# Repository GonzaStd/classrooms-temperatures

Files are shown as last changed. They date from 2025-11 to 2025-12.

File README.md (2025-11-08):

> [!IMPORTANT]  
> This project has been made for a specific purpose. If you want to replicate this, you would have to ADAPT IT. However, example code and circuit documentation are provided below on the index, and they are for general use. 

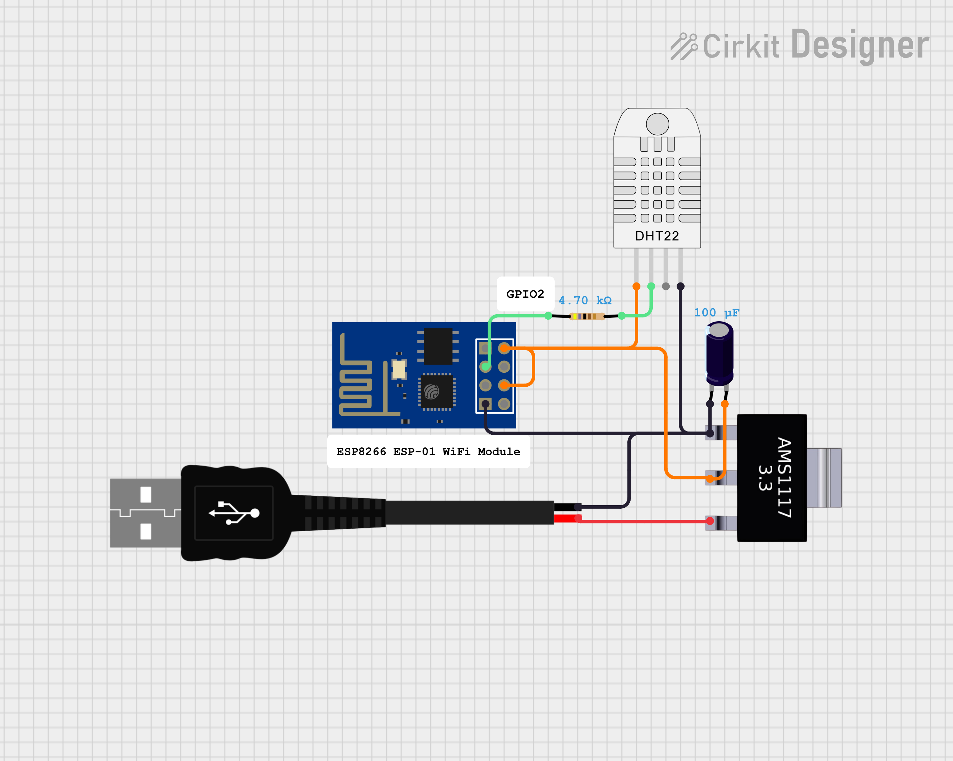
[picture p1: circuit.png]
Circuit diagram


[Here](https://app.cirkitdesigner.com/project/02f16717-05df-46d2-9647-529fff1c8d03) is the url of the circuit.

### Index
* [Circuit Explaination](docs/circuit.md)
* [Example code for general use](docs/example-code.md)

## Context
With the purpose of measuring the temperature of classrooms in our school (and so the thermal discomfort), I've made this project that connects esp-01 modules that act like mqtt clients that publishes temperature and humidity, and by the other side subscribes to a topic they use to know WHEN to send data. 

On the other hand, we'll need a broker, in this case I'll use a Raspberry Pi. This one has to send a request to their clients, receive temperature and humidity, then upload the data to a Google Spreadsheet. 

After a few months, this data will be used to analyse the thermal discomfort and then a request will be sent asking the authorities to allow the placement of rotating fans and curtains (currently there are few fans, they do not rotate and there are no curtains).

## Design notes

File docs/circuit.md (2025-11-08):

# Circuit documentation

## Summary

This circuit interfaces an ESP8266 ESP-01 Wi‑Fi module with a DHT22 temperature & humidity sensor. The ESP8266 connects to Wi‑Fi and publishes sensor readings to an MQTT broker. Power comes from USB and is regulated to 3.3V using an AMS1117. A pull-up resistor is used on the DHT22 data line.

## Components

1. ESP8266 ESP-01
	- Description: Small Wi‑Fi module used to connect to a network and run the MQTT client.
	- Pins: `TXD`, `CH_PD`, `RST`, `VCC`, `GND`, `GPIO_2`, `GPIO_0`, `RXD`

2. DHT22 (temperature & humidity sensor)
	- Description: Digital temperature and humidity sensor.
	- Pins: `VCC`, `DATA`, `NC`, `GND`

3. Pull-up resistor (for DHT22 data line)
	- Description: Pull-up resistor for the DHT22 data line.
	- Value: 4.7 kΩ (4700 Ω)
	- Pins: `pin1`, `pin2`

4. USB 2‑pin power connector
	- Description: Provides 5V power from a USB source.
	- Pins: `V+` (Positive), `GND` (Negative)

5. AMS1117 3.3V regulator
	- Description: Regulates USB 5V down to 3.3V for the ESP8266 and sensor.
	- Pins: `GND`, `OUT` (3.3V), `IN` (5V)

6. Electrolytic capacitor
	- Description: Voltage stabilization on the regulator output.
	- Typical value: 100 µF (0.0001 F)
	- Polarity: `-` (negative), `+` (positive)

## Wiring details

### ESP8266 (ESP-01)
 - `GND`: connect to regulator GND, USB GND, DHT22 GND, and capacitor `-`.
 - `CH_PD` (chip enable): tie to `VCC` (3.3V).
 - `VCC`: connect to AMS1117 `OUT` (3.3V).
 - `GPIO_0`: used for programming mode; if used for the DHT/data wiring follow your firmware wiring (commonly not used by the DHT data line). Ensure correct logic level for boot.

### DHT22
 - `VCC`: connect to AMS1117 `OUT` (3.3V).
 - `DATA`: connect to the microcontroller data pin through a pull-up resistor (4.7 kΩ to 3.3V).
 - `GND`: connect to system GND.

### Pull-up resistor
 - `pin1`: connected to the DHT22 `DATA` line (or microcontroller input if placed there).
 - `pin2`: connected to `VCC` (3.3V) as the pull-up.

### USB power connector
 - `GND` (Negative): connect to system GND.
 - `V+` (Positive): connect to AMS1117 `IN` (5V from USB).

### AMS1117 3.3V regulator
 - `GND`: system ground.
 - `OUT`: 3.3V output — connect to ESP8266 `VCC`, DHT22 `VCC`, capacitor `+`.
 - `IN`: 5V input from USB `V+`.

### Electrolytic capacitor
 - `-` (negative): connect to system GND.
 - `+` (positive): connect to AMS1117 `OUT` (3.3V) for smoothing.

---

Notes:
- Use a common ground for all modules.
- The DHT22 data line requires a pull-up (4.7 kΩ is a standard choice). Place the pull-up between DATA and 3.3V.
- Ensure the ESP8266 receives a stable 3.3V supply and that the regulator can supply sufficient current (ESP8266 can spike during Wi‑Fi transmissions).

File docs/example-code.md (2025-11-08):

# Generic and example code
This code is an example of what you could use to flash the ESP-01 firmware and use it with the circuit shown below. This is NOT the code upload on this repository, this is for general use.

```cpp
#include <ESP8266WiFi.h>
#include <PubSubClient.h>
#include <DHT.h>

#define DHTPIN D2          // Pin where the DHT22 is connected
#define DHTTYPE DHT22     // DHT 22 (AM2302)

// Wi-Fi credentials
const char* ssid = "yourSSID";
const char* password = "yourPASSWORD";

// MQTT server details
const char* mqttServer = "mqttServer";
const int mqttPort = 1883; // Default MQTT port
const char* topic = "sensor/data";

DHT dht(DHTPIN, DHTTYPE);
WiFiClient espClient;
PubSubClient client(espClient);

void setup() {
  Serial.begin(9600);
  dht.begin();
  setupWiFi();
  client.setServer(mqttServer, mqttPort);
}

void setupWiFi() {
  delay(10);
  Serial.println();
  Serial.print("Connecting to ");
  Serial.println(ssid);
  
  WiFi.begin(ssid, password);
  
  while (WiFi.status() != WL_CONNECTED) {
    delay(500);
    Serial.print(".");
  }
  
  Serial.println();
  Serial.println("WiFi connected");
}

void loop() {
  if (!client.connected()) {
    reconnect();
  }
  client.loop();

  float h = dht.readHumidity();
  float t = dht.readTemperature();

  if (isnan(h) || isnan(t)) {
    Serial.println("Failed to read from DHT sensor!");
    return;
  }

  String payload = String("Temperature: ") + t + " °C, Humidity: " + h + " %";
  client.publish(topic, payload.c_str());
  
  delay(2000); // Publish every 2 seconds
}

void reconnect() {
  while (!client.connected()) {
    Serial.print("Attempting MQTT connection...");
    if (client.connect("ESP8266Client")) {
      Serial.println("connected");
    } else {
      Serial.print("failed, rc=");
      Serial.print(client.state());
      Serial.println(" try again in 5 seconds");
      delay(5000);
    }
  }
}
```

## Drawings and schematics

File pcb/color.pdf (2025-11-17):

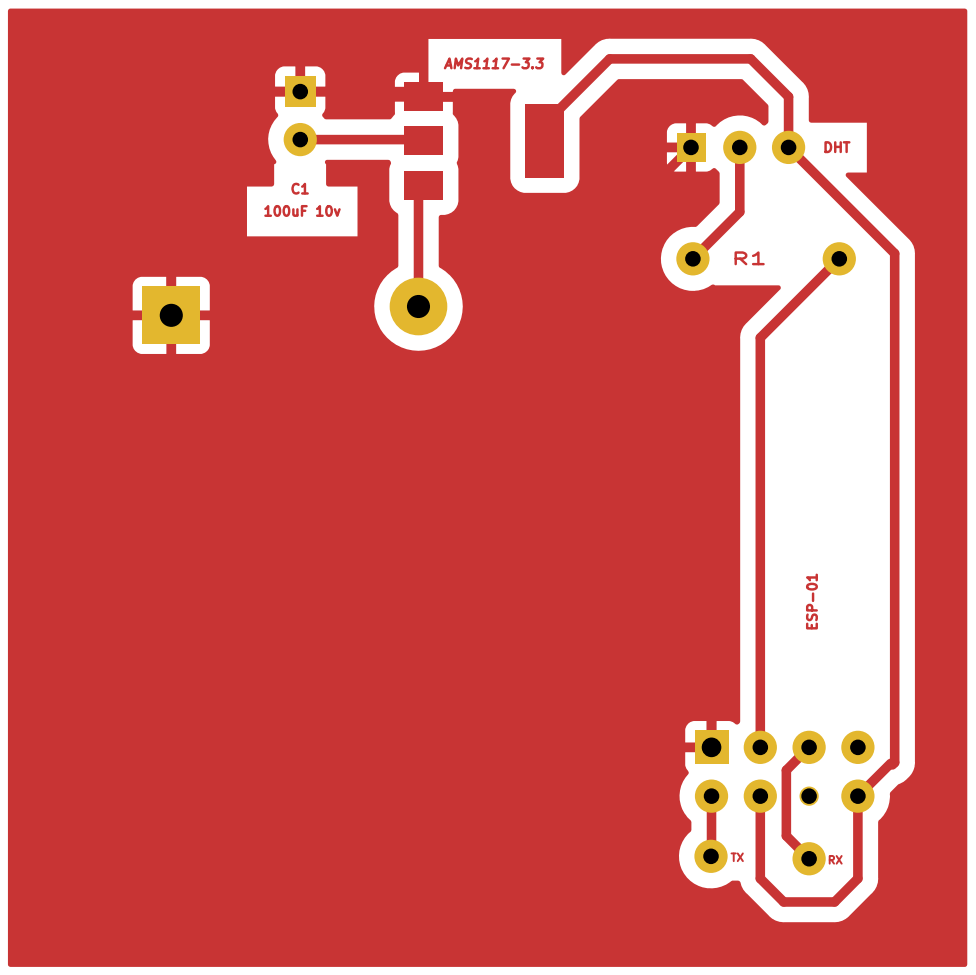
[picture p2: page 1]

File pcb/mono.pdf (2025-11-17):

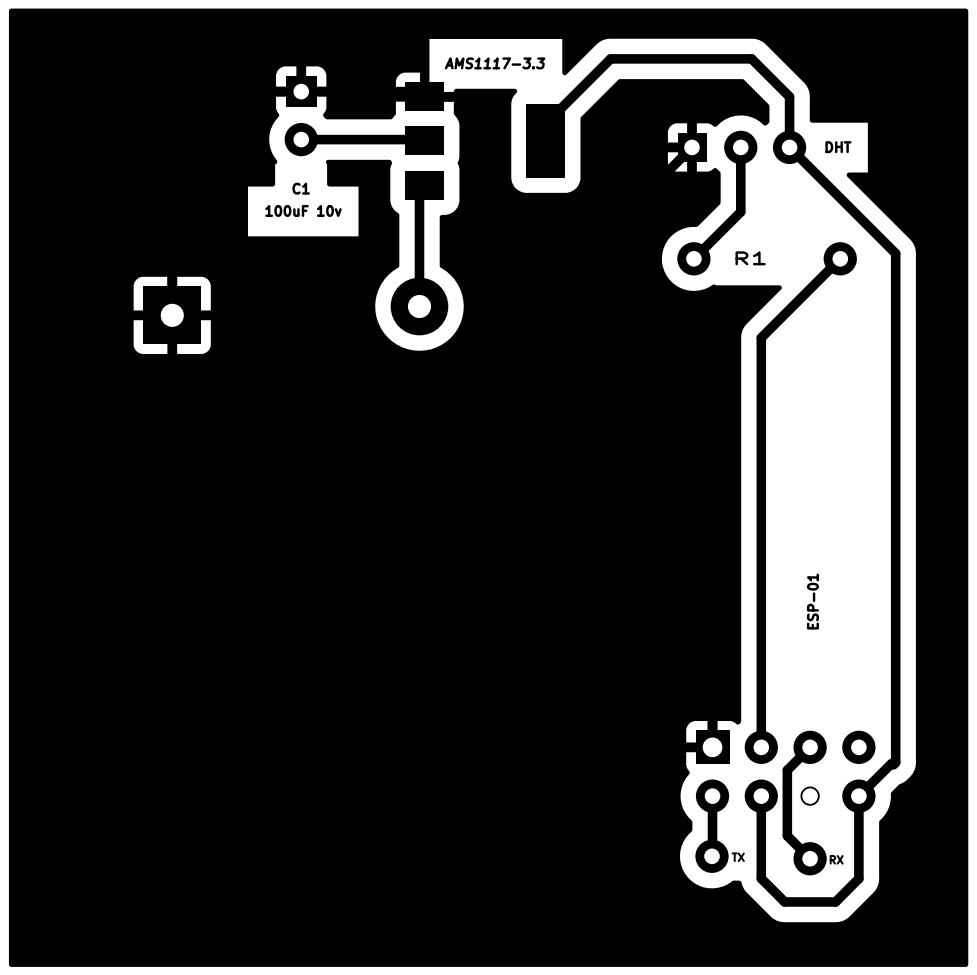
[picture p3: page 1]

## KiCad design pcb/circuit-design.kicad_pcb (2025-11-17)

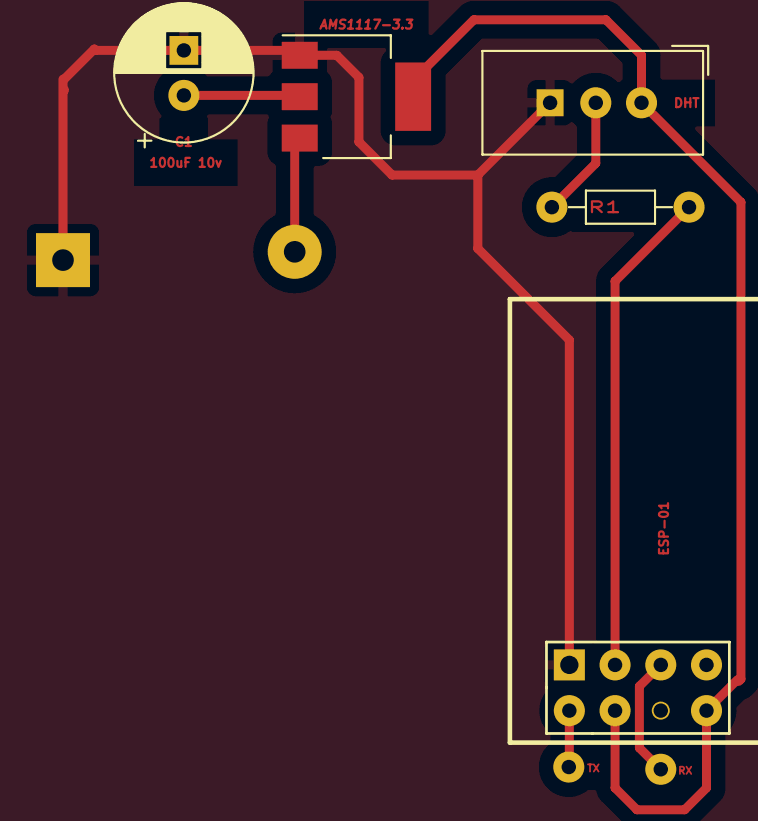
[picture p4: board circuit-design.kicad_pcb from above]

Board: 2 copper layers, 5 parts (0 on the bottom side), 4 nets.

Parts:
C1: 100uF 10v; CP_Radial_D7.5mm_P2.50mm
DHT: DHT; three_pin_DHT11_5.5x12.0_P2.54mm
R1: 4.7kOhm; R_Axial_DIN0204_L3.6mm_D1.6mm_P7.62mm_Horizontal
U1: ESP-01
U2: AMS1117-3.3; SOT-223-3_TabPin2

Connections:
+3V3: C1.1, DHT.1 (VCC), U1.3 (CH_PD), U1.7 (VCC), U2.2 (VO)
GND: C1.2, DHT.3 (NC), U1.2 (GND), U2.1 (GND)
unnamed: DHT.2 (IO), R1.1
unnamed: R1.2, U1.4 (GPIO2)

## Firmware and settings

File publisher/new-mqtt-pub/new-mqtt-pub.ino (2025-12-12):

/* ESP-01 (ESP8266EX) - NTP schedule + DHT11 + MQTT (PubSubClient)
   - Arduino Core (ESP8266)
   - Serial 9600 (según tu ESP-01)
   - DHT11 en GPIO2 (define DHTPIN abajo como 2)
   - DHCP (WiFi.begin(ssid, pass))
   - Reintentos NTP: 10 intentos, timeout 5s por intento
   - Si NTP falla -> deepSleep 3 horas
   - Schedule: {8,11,14,17,20,23} (horas locales UTC-3)
   - Uso: conectar GPIO16 <-> RST mediante SOLDER JUMPER para poder wakeup; abrir jumper al flashear (ver explicación abajo).
*/

#include <ESP8266WiFi.h>
#include <WiFiUdp.h>
#include <ESP8266HTTPClient.h>
#include <PubSubClient.h>
#include <DHT.h>

#include <stdint.h>

#define SERIAL_BAUD 9600
#define DHTPIN 2            // GPIO2 (ajustalo si preferís otro pin; en ESP-01 son limitados)
#define DHTTYPE DHT11

// ----- CONFIGURAR -----
const char* ssid = "BA Escuela";       // tu SSID (red con portal)
const char* wifi_user = "";            // si tu auth lo requiere en código (si no, dejá vacío)
const char* wifi_pass = "";            // lo manejás en el segundo código: deja aquí si querés
const char* mqttServer = "not-known-yet"; // <- COMPLETAR
const uint16_t mqttPort = 1883;       // sin TLS
const char* mqttUser = "raspberrypi"; // <- COMPLETAR si aplica
const char* mqttPass = "Hacemuchocalor"; // <- COMPLETAR si aplica

const char* probeUrl = "http://detectportal.firefox.com/canonical.html"; // portal detection
const char* topic = "aula/1"; // minimal payload; cambia por sensor por dispositivo

// NTP servers
const char* NTP_SERVERS[] = {
  "0.south-america.pool.ntp.org",
  "1.south-america.pool.ntp.org",
  "2.south-america.pool.ntp.org",
  "3.south-america.pool.ntp.org",
  "pool.ntp.org",
  "0.pool.ntp.org",
  "1.pool.ntp.org"
};
const int NTP_SERVERS_COUNT = sizeof(NTP_SERVERS)/sizeof(NTP_SERVERS[0]);

const int MAX_NTP_ATTEMPTS = 10;
const unsigned long NTP_ATTEMPT_TIMEOUT_MS = 5000UL; // 5s
const unsigned long NTP_RETRY_DELAY_MS = 200UL;      // pequeño gap entre solicitudes
const uint64_t FAIL_SLEEP_MICROS = (uint64_t)3ULL * 3600ULL * 1000000ULL; // 3h en micros

// schedule horas 24h
const uint8_t scheduleHours[] = {8, 11, 14, 17, 20, 23};
const int SCHEDULE_LEN = sizeof(scheduleHours)/sizeof(scheduleHours[0]);

// timezone Argentina UTC-3 fijo
const int TZ_OFFSET_SECONDS = -3 * 3600;

// objetos globales
WiFiUDP udp;
DHT dht(DHTPIN, DHTTYPE);
WiFiClient espClient;
PubSubClient mqttClient(espClient);

// helpers NTP
const int NTP_PACKET_SIZE = 48;
byte ntpPacketBuffer[NTP_PACKET_SIZE];

// Construye paquete NTP
void sendNTPpacket(const char* address) {
  memset(ntpPacketBuffer, 0, NTP_PACKET_SIZE);
  ntpPacketBuffer[0] = 0b11100011; // LI, VN, Mode (v4, client)
  udp.beginPacket(address, 123);
  udp.write(ntpPacketBuffer, NTP_PACKET_SIZE);
  udp.endPacket();
}

// Pide NTP y devuelve true con epochUnix (segundos unix UTC) si OK
bool requestNTP(const char* server, uint32_t &epochUnix, unsigned long timeoutMs) {
  udp.beginPacket(server, 123);
  memset(ntpPacketBuffer, 0, NTP_PACKET_SIZE);
  ntpPacketBuffer[0] = 0b11100011;
  udp.write(ntpPacketBuffer, NTP_PACKET_SIZE);
  udp.endPacket();

  unsigned long start = millis();
  while (millis() - start < timeoutMs) {
    int len = udp.parsePacket();
    if (len >= NTP_PACKET_SIZE) {
      udp.read(ntpPacketBuffer, NTP_PACKET_SIZE);
      uint32_t seconds1900 = (uint32_t)ntpPacketBuffer[40] << 24 |
                             (uint32_t)ntpPacketBuffer[41] << 16 |
                             (uint32_t)ntpPacketBuffer[42] << 8  |
                             (uint32_t)ntpPacketBuffer[43];
      const uint32_t NTP_TO_UNIX = 2208988800UL;
      if (seconds1900 == 0 || seconds1900 <= NTP_TO_UNIX) return false;
      epochUnix = seconds1900 - NTP_TO_UNIX;
      return true;
    }
    delay(10);
  }
  return false;
}

// Sincroniza con varios intentos (round-robin servers). Devuelve true y setea epochUnixUTC.
bool syncNTPWithRetries(uint32_t &epochUnixUTC) {
  for (int attempt = 0; attempt < MAX_NTP_ATTEMPTS; ++attempt) {
    const char* server = NTP_SERVERS[attempt % NTP_SERVERS_COUNT];
    Serial.printf("NTP intento %d -> %s\n", attempt + 1, server);
    uint32_t got = 0;
    if (requestNTP(server, got, NTP_ATTEMPT_TIMEOUT_MS)) {
      epochUnixUTC = got;
      return true;
    }
    Serial.println("NTP no respondió (o no válido).");
    delay(NTP_RETRY_DELAY_MS);
  }
  return false;
}

// Convierte epoch UTC a segundos desde medianoche local (0..86399)
uint32_t secondsSinceMidnightLocal(uint32_t epochUnixUTC) {
  int64_t localEpoch = (int64_t)epochUnixUTC + (int64_t)TZ_OFFSET_SECONDS;
  uint32_t secondsOfDay = (uint32_t)((localEpoch % 86400 + 86400) % 86400);
  return secondsOfDay;
}

// Calcula segundos faltantes hasta 'hour:00:00' (ajusta +24h si ya pasó). Devuelve segundos (no micros)
uint64_t secondsUntilHour(uint32_t currentSeconds, uint8_t hour) {
  uint32_t target = (uint32_t)hour * 3600U;
  int64_t diff = (int64_t)target - (int64_t)currentSeconds;
  if (diff <= 0) diff += 24LL * 3600LL;
  return (uint64_t)diff;
}

// Calcula microsegundos hasta el siguiente horario del arreglo
uint64_t computeSleepMicros(uint32_t currentSeconds) {
  for (int i = 0; i < SCHEDULE_LEN; ++i) {
    uint8_t h = scheduleHours[i];
    uint64_t secs = secondsUntilHour(currentSeconds, h);
    // el primer horario con secs>0 será el objetivo (incluye caso wrap)
    if (secs > 0) {
      return secs * 1000000ULL;
    }
  }
  // fallback: 24h
  return (uint64_t)24ULL * 3600ULL * 1000000ULL;
}

// Detecta portal cautivo: hace GET al probeUrl y si hay redirección devuelve true
bool detectPortal() {
  HTTPClient http;
  WiFiClient httpClient;
  if (!http.begin(httpClient, probeUrl)) {
    return false;
  }
  http.addHeader("User-Agent", "Mozilla/5.0");
  int code = http.GET();
  http.end();
  // Redirección 3xx suele indicar portal; suponer 3xx => portal
  return (code >= 300 && code < 400);
}

// Ensure MQTT connected (sin TLS). Reintenta hasta publicar con exito (intentos limitados).
bool mqttPublishWithRetry(const char* topic, const char* payload, int maxAttempts = 5) {
  int attempts = 0;
  while (attempts < maxAttempts) {
    if (!mqttClient.connected()) {
      String clientId = "ESP-" + String(ESP.getChipId());
      Serial.print("Conectando MQTT...");
      if (mqttClient.connect(clientId.c_str(), mqttUser, mqttPass)) {
        Serial.println("OK");
      } else {
        Serial.printf("Fallo MQTT state=%d. Retry...\n", mqttClient.state());
        delay(2000);
        attempts++;
        continue;
      }
    }
    if (mqttClient.publish(topic, payload)) {
      Serial.println("Publicado MQTT OK");
      return true;
    } else {
      Serial.println("Publish fallo. Reintentando...");
      attempts++;
      delay(1000);
    }
  }
  return false;
}

void setup() {
  Serial.begin(SERIAL_BAUD);
  delay(100);
  Serial.println("\n=== Inicio ESP-01: schedule NTP + DHT11 + MQTT ===");

  dht.begin();

  // Limpieza WiFi previa
  WiFi.disconnect(true);
  WiFi.mode(WIFI_STA);

  // ----- Conectar WiFi (DHCP) -----
  Serial.printf("Conectando a SSID '%s' ...\n", ssid);
  if (strlen(wifi_pass) > 0) {
    WiFi.begin(ssid, wifi_pass);
  } else {
    WiFi.begin(ssid); // red que maneja auth por portal
  }

  unsigned long start = millis();
  while (WiFi.status() != WL_CONNECTED && millis() - start < 20000UL) {
    delay(200);
    Serial.print(".");
  }
  Serial.println();

  if (WiFi.status() == WL_CONNECTED) {
    Serial.println("WiFi conectado.");
    Serial.print("IP: ");
    Serial.println(WiFi.localIP());
  } else {
    Serial.println("WiFi NO conectado (seguiré intentando NTP igual; puede fallar).");
  }

  // Iniciar UDP para NTP
  udp.begin(2390);

  // Intentar NTP (hasta MAX_NTP_ATTEMPTS)
  uint32_t epochUTC = 0;
  bool ntpOk = syncNTPWithRetries(epochUTC);
  if (!ntpOk) {
    Serial.println("NTP falló tras varios intentos. Entrando en deep sleep 3 horas.");
    delay(50);
    ESP.deepSleep((uint64_t)FAIL_SLEEP_MICROS);
    // no vuelve aquí
    return;
  }

  // Obtener hora local (h:m:s) aproximada
  uint32_t secondsLocal = secondsSinceMidnightLocal(epochUTC);
  uint32_t hour = secondsLocal / 3600;
  uint32_t minute = (secondsLocal % 3600) / 60;
  uint32_t second = secondsLocal % 60;
  Serial.printf("Hora local aproximada: %02u:%02u:%02u\n", hour, minute, second);

  // Detectar portal cautivo -> si hay portal: no publicar MQTT
  bool portal = detectPortal();
  if (portal) {
    Serial.println("Portal cautivo DETECTADO. No publicar MQTT en este ciclo.");
  } else {
    // Leer DHT (solo si tenemos sensor y la lectura es válida)
    float h = dht.readHumidity();
    float t = dht.readTemperature();
    if (!isnan(h) && !isnan(t)) {
      // Preparar payload minimalista (solo topic — tu servidor distinguirá por topic)
      // Como pediste minimal: mandamos temperatura y humedad en un string simple
      char payload[64];
      snprintf(payload, sizeof(payload), "{\"t\":%.1f,\"h\":%.1f}", t, h);
      Serial.print("Payload: ");
      Serial.println(payload);

      // MQTT config y publicar (sin TLS). Intentos internos para asegurar llegada
      mqttClient.setServer(mqttServer, mqttPort);
      if (!mqttPublishWithRetry(topic, payload, 6)) {
        Serial.println("No se pudo publicar por MQTT después de reintentos.");
      }
      // desconectar para ahorrar energía (PubSubClient no tiene disconnect, se puede call client.disconnect)
      mqttClient.disconnect();
    } else {
      Serial.println("Lectura DHT fallida: no se publicará.");
    }
  }

  // Calcular tiempo restante hasta próximo schedule
  uint64_t sleepMicros = computeSleepMicros(secondsLocal);
  Serial.printf("Durmiendo %llu micros (aprox %.2f h)\n", (unsigned long long)sleepMicros, (double)sleepMicros / 1.0e6 / 3600.0);
  delay(50);

  // Deep Sleep -> requiere GPIO16 (XPD) conectado a RST para wakeup
  ESP.deepSleep(sleepMicros);
}

void loop() {
  // no se usa
}

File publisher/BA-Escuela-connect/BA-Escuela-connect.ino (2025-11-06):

#include <ESP8266WiFi.h>
#include <WiFiClientSecure.h>
#include <ESP8266HTTPClient.h>

// --- Config ---
const char* SSID = "BA Escuela";
const char* PROBE_URL = "http://detectportal.firefox.com/canonical.html";
const char* USER_AGENT = "Mozilla/5.0 (X11; Linux x86_64; rv:140.0) Gecko/20100101 Firefox/140.0";

// --- util: mostrar headers ---
void dumpResponseHeaders(HTTPClient &hc) {
  int nh = hc.headers();
  Serial.printf("Headers recibidos: %d\n", nh);
  for (int i = 0; i < nh; ++i) {
    String name = hc.headerName(i);
    String val  = hc.header(i);
    Serial.printf("  [%d] %s: %s\n", i, name.c_str(), val.c_str());
  }
}

// --- probe detect portal ---
String probeDetectPortal() {
  HTTPClient http;
  WiFiClient client;
  http.setTimeout(7000);
  if (!http.begin(client, PROBE_URL)) {
    Serial.println("http.begin falló (probe)");
    return String();
  }
  http.addHeader("User-Agent", USER_AGENT);
  http.addHeader("Accept", "*/*");
  http.addHeader("Cache-Control", "no-cache");
  http.addHeader("Pragma", "no-cache");

  int code = http.GET();
  Serial.printf("Probe HTTP code: %d\n", code);
  dumpResponseHeaders(http);

  // intentar Location header
  if (code >= 300 && code < 400) {
    String loc = http.header("Location");
    if (loc.length()) {
      Serial.println("Location encontrado (header): " + loc);
      http.end();
      return loc;
    }
  }

  // fallback: buscar en body <LoginURL> o https://.../splash/
  String body = http.getString();
  int p = body.indexOf("<LoginURL>");
  if (p >= 0) {
    int start = p + strlen("<LoginURL>");
    int end = body.indexOf("</LoginURL>", start);
    if (end > start) {
      String loginurl = body.substring(start, end);
      Serial.println("LoginURL extraído del XML: " + loginurl);
      http.end();
      return loginurl;
    }
  }
  p = body.indexOf("https://");
  if (p >= 0) {
    int q = body.indexOf('"', p);
    if (q < 0) q = body.indexOf('\'', p);
    if (q < 0) q = body.length();
    String candidate = body.substring(p, q);
    if (candidate.indexOf("/splash/") >= 0 || candidate.indexOf("network-auth.com") >= 0) {
      Serial.println("Posible splash extraído del body: " + candidate);
      http.end();
      return candidate;
    }
  }

  Serial.println("No se extrajo URL del portal.");
  http.end();
  return String();
}

// --- HEAD para Continue-Url ---
String headGetContinueUrl(const String &location) {
  if (location.length() == 0) return String();
  WiFiClientSecure wcs;
  wcs.setInsecure();
  HTTPClient https;
  https.setTimeout(7000);
  if (!https.begin(wcs, location)) {
    Serial.println("begin HEAD falló para: " + location);
    return String();
  }
  https.addHeader("User-Agent", USER_AGENT);
  https.addHeader("X-Requested-With", "XMLHttpRequest");

  int code = https.sendRequest("HEAD");
  Serial.printf("HEAD code: %d\n", code);
  dumpResponseHeaders(https);

  String cont = https.header("Continue-Url");
  if (cont.length() == 0) cont = https.header("Continue-url");
  if (cont.length() == 0) cont = https.header("continue-url");

  if (cont.length()) {
    Serial.println("Continue-Url (header): " + cont);
    https.end();
    return cont;
  }

  // fallback: GET corto
  int code2 = https.GET();
  Serial.printf("GET fallback code: %d\n", code2);
  dumpResponseHeaders(https);
  if (code2 > 0) {
    String body = https.getString();
    int p = body.indexOf("Continue-Url");
    if (p >= 0) {
      int colon = body.indexOf(':', p);
      if (colon > 0) {
        int eol = body.indexOf('\n', colon);
        if (eol < 0) eol = body.length();
        String val = body.substring(colon+1, eol);
        val.trim();
        //Serial.println("Continue-Url extraído del body: " + val);
        https.end();
        return val;
      }
    }
    p = body.indexOf("http");
    if (p >= 0) {
      int q = body.indexOf('"', p);
      if (q < 0) q = body.indexOf('\'', p);
      if (q < 0) q = body.length();
      String candidate = body.substring(p, q);
      //Serial.println("Candidate Continue-url from body: " + candidate);
      https.end();
      return candidate;
    }
  }

  https.end();
  return String();
}

// --- Setup ---
void setup() {
  Serial.begin(9600);
  delay(1000);
  WiFi.mode(WIFI_STA);
  WiFi.disconnect(true);
  delay(1000);
  Serial.println("We are about to begin. WiFi status: ");
  Serial.println(WiFi.status());
  Serial.println("WiFi networks: ");
  Serial.println(WiFi.scanNetworks());

  
  WiFi.begin(SSID);

  Serial.print("Conectando a WiFi...");
  int t = 0;
  while (WiFi.status() != WL_CONNECTED && t < 20) {
    delay(500); Serial.print(".");
    t++;
  }
  Serial.println();

  if (WiFi.status() != WL_CONNECTED) {
    Serial.println("No se pudo conectar al WiFi.");
    return;
  }
  Serial.println("Conectado. IP: " + WiFi.localIP().toString());

  // probe
  String splashURL = probeDetectPortal();
  if (splashURL.length() == 0) {
    Serial.println("No hubo redirect. Puede que ya estés autenticado o gateway no intercepta.");
    return;
  }
  //Serial.println("URL Splash detectada: " + splashURL);

  // HEAD para Continue-UrlSerial.print
  String continueUrl = headGetContinueUrl(splashURL);
  Serial.println("Continue-Url final: " + continueUrl);
}

void loop() {
  // nada por ahora
}

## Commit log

2025-11-06 Better setup, localhost for broker, wifi connect working and without debugging prints.
    [BA-Escuela-connect.ino]
2025-11-08 Circuit updated
2025-11-15 PCB ready. I took me 2 hours and 48 minutes
    [circuit-design.kicad_pcb, circuit-design.kicad_sch]
2025-11-17 Fixed something missing and improved a better visibility
    [circuit-design.kicad_pcb]
2025-12-12 New code without making any probe.
